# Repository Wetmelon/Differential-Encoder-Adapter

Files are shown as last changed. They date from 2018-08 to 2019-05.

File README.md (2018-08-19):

# Differential Encoder Adapter

This project is dedicated to a simple adapter board designed to convert 5V line driver encoders to single-ended encoders for use with the ODrive 3.x servo driver.

[Order Boards Here](https://oshpark.com/shared_projects/JfDf458t)

[BOM on Octopart available here](https://octopart.com/bom-tool/bUMGyQwH)

MIT License

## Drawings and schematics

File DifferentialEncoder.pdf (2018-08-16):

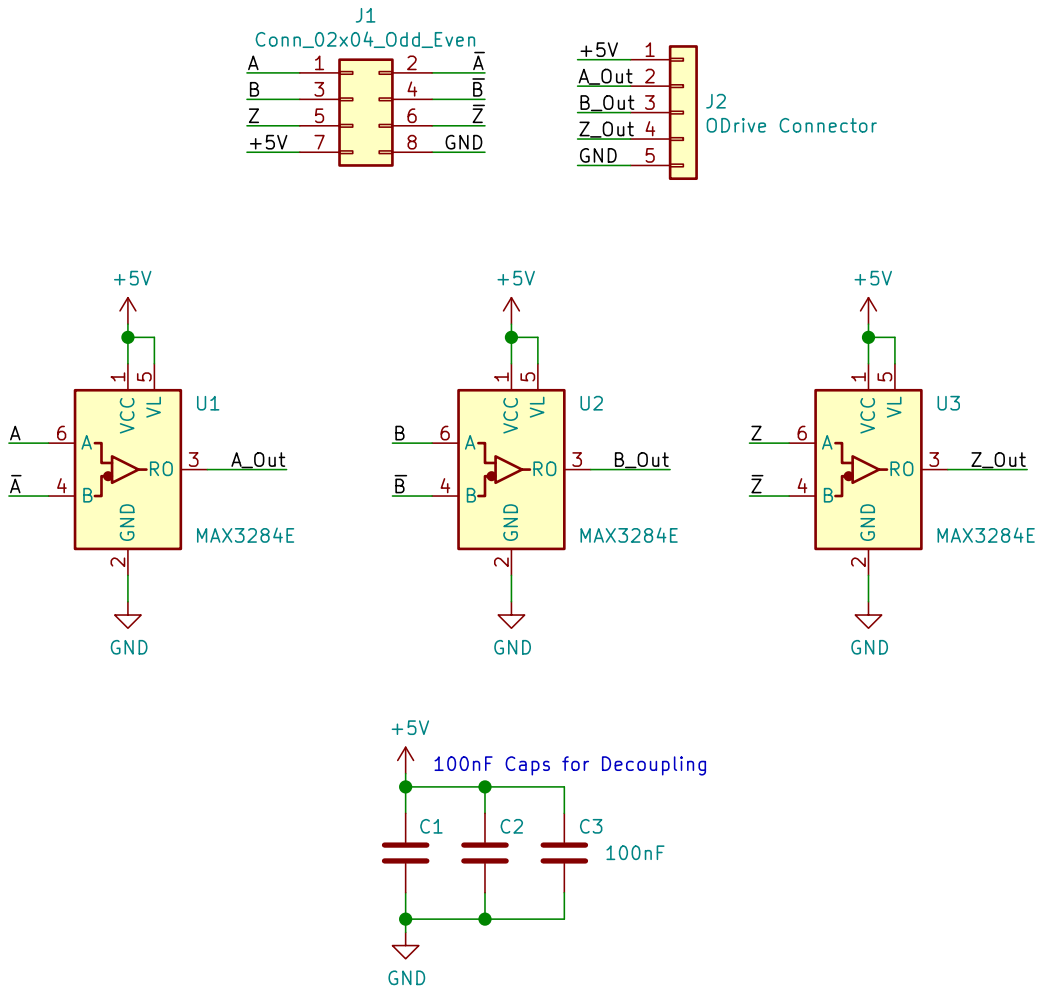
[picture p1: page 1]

1 GND
Id: 1/1 Title: ODrive Differential Encoder Adapter File: DifferentialEncoder.sch Sheet: / Melonwerks Wetmelon VCC

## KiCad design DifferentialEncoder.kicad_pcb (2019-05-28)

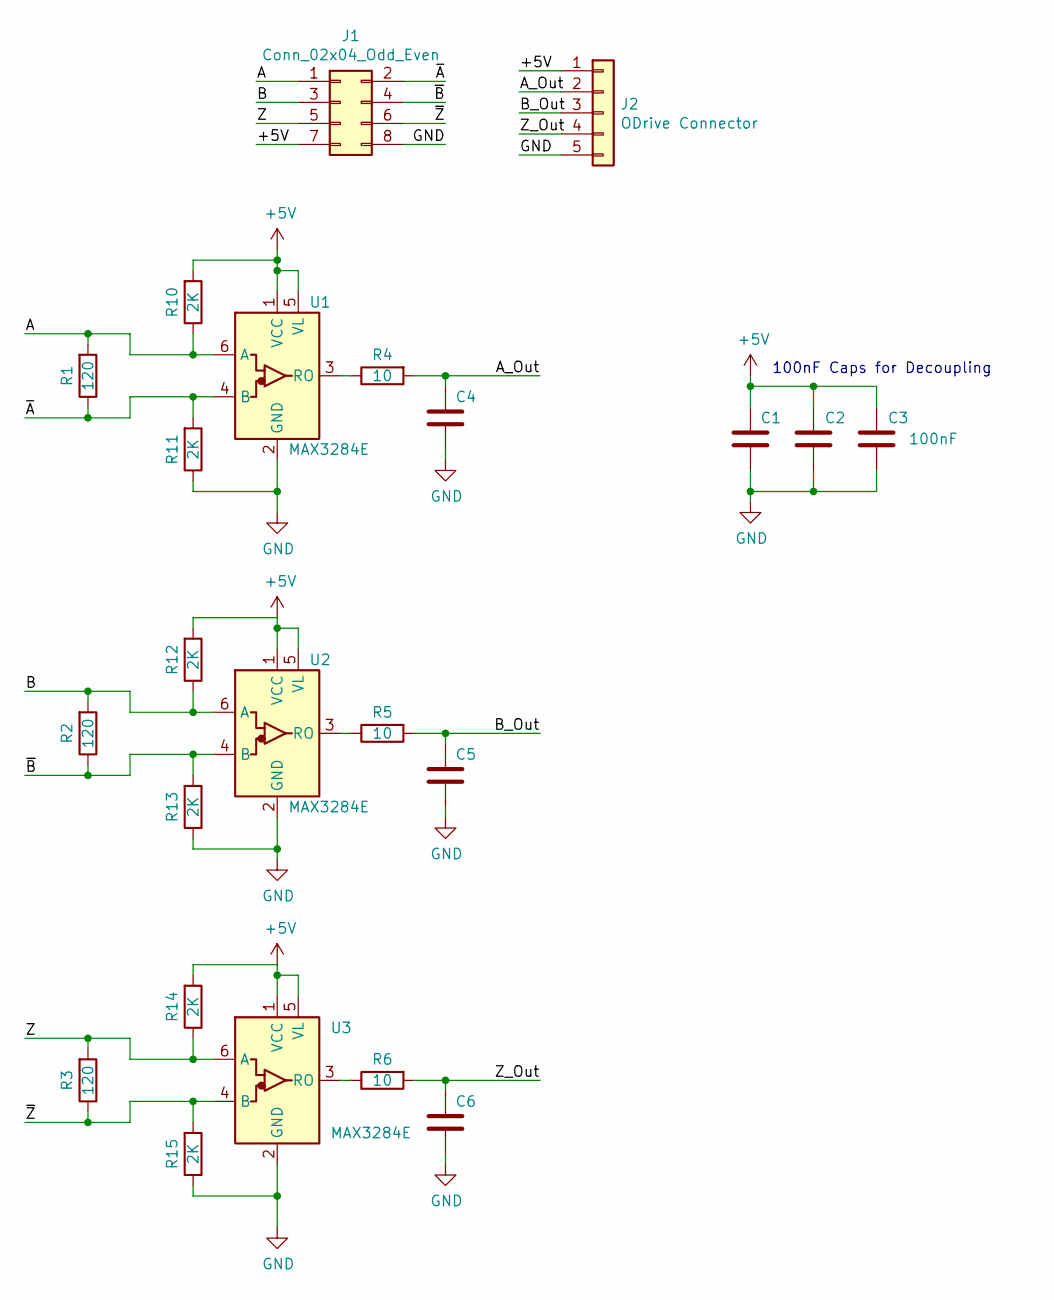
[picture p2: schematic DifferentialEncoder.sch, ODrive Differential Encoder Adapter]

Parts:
C1, C2, C3: 100nF; C_0805_2012Metric
C4, C5, C6: 1nF; C_0805_2012Metric
J1: Conn_02x04_Odd_Even; PinHeader_2x04_P2.54mm_Vertical
J2: ODrive Connector; PinHeader_1x05_P2.54mm_Vertical
R1, R2, R3: 120; R_0805_2012Metric_Pad1.15x1.40mm_HandSolder
R4, R5, R6: 10; R_0805_2012Metric_Pad1.15x1.40mm_HandSolder
R10, R11, R12, R13, R14, R15: 2K; R_0805_2012Metric_Pad1.15x1.40mm_HandSolder
U1, U2, U3: MAX3284E; SOT-23-6

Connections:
+5V: C1.1, C2.1, C3.1, J1.7, J2.1, R10.2, R12.2, R14.2, U1.1 (VCC), U1.5 (VL), U2.1 (VCC), U2.5 (VL), U3.1 (VCC), U3.5 (VL)
/A: J1.1, R1.2, R10.1, U1.6 (A)
/A_Out: C4.1, J2.2, R4.2
/B: J1.3, R2.2, R12.1, U2.6 (A)
/B_Out: C5.1, J2.3, R5.2
/Z: J1.5, R3.2, R14.1, U3.6 (A)
/Z_Out: C6.1, J2.4, R6.2
/~A: J1.2, R1.1, R11.2, U1.4 (B)
/~B: J1.4, R2.1, R13.2, U2.4 (B)
/~Z: J1.6, R3.1, R15.2, U3.4 (B)
GND: C1.2, C2.2, C3.2, C4.2, C5.2, C6.2, J1.8, J2.5, R11.1, R13.1, R15.1, U1.2 (GND), U2.2 (GND), U3.2 (GND)
unnamed: R4.1, U1.3 (RO)
unnamed: R5.1, U2.3 (RO)
unnamed: R6.1, U3.3 (RO)

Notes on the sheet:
100nF Caps for Decoupling

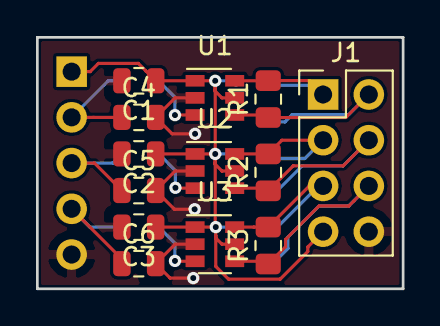
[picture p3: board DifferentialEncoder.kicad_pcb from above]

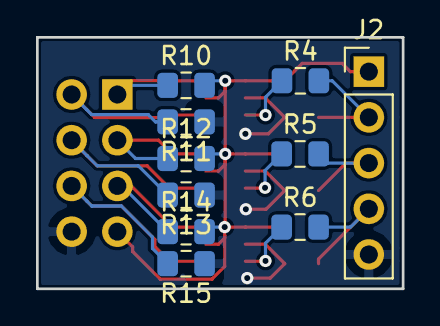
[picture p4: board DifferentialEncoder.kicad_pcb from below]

Board: 2 copper layers, 20.3 x 14.0 mm, 23 parts (10 on the bottom side), 14 nets.

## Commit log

2018-08-16 Create Revision 1
    [DifferentialEncoder.kicad_pcb, DifferentialEncoder.sch]
2018-08-19 Change some silkscreen, flip single-ended pins to back side
    [DifferentialEncoder.kicad_pcb]
2019-05-28 Update differential adapter with termination etc.
    [DifferentialEncoder.kicad_pcb, DifferentialEncoder.sch]
